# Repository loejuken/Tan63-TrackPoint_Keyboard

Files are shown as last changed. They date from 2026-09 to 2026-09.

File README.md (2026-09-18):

# Tan63

## Building a Trackpoint HHKB Mechanical Keyboard

AKA The ultimate larper keyboard for maximizing productivity
... but ending up just making everything more complicated lol

I love this project though

PCB, Case, and plate are finished. Case and plate CAD files will be uploaded at some point.
I may make a version 2 of the case before uploading to update some design choices and optimize for CNC.

Will upload finished images after final soldering fixes are done. Waiting for time to visit my makerspace nearby.
I've been a bit busy with school

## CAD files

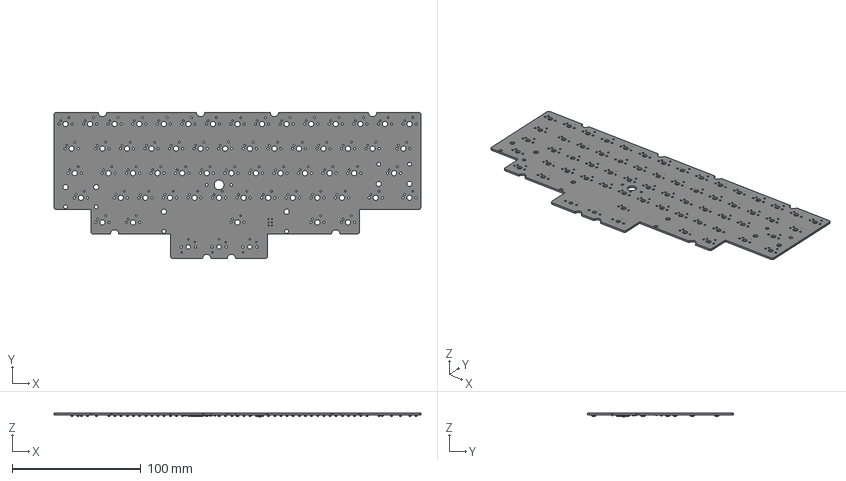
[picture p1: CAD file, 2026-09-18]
pcb.step
284.5 x 113.1 x 3.09 mm
R_0603_1608Metric x 7
D_SOD-123 x 63
C_0603_1608Metric x 8
TQFP-44_10x10mm_P0.8mm
SW_SPST_SKQG_WithStem
Crystal_SMD_3225-4Pin_3.2x2.5mm
ai03-pcb-guide_PCB

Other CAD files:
tan63.FCStd

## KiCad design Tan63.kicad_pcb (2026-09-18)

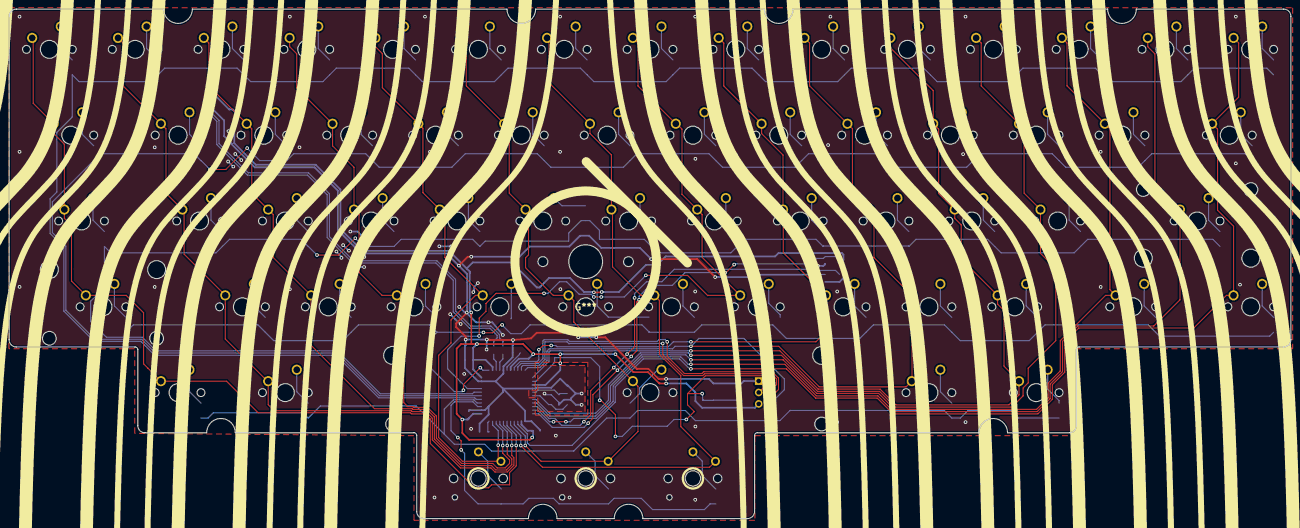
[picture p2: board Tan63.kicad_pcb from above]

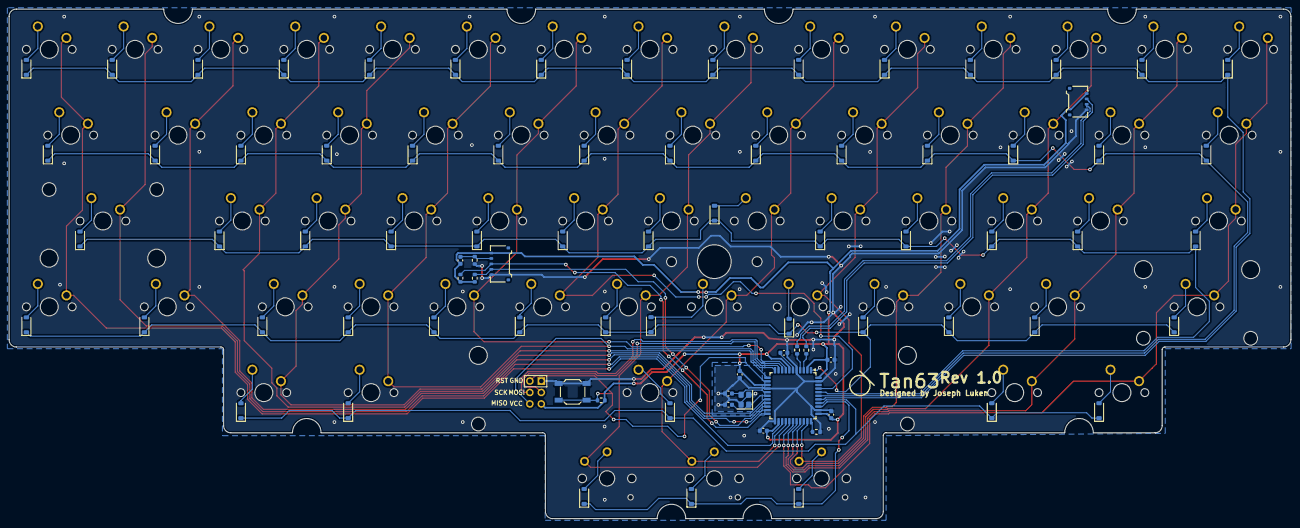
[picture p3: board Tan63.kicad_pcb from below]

Board: 2 copper layers, 284.5 x 113.1 mm, 147 parts (84 on the bottom side), 100 nets.

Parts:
C1, C2: 22pF; C_0603_1608Metric
C3: 1uF; C_0603_1608Metric
C4, C5, C6: 0.1uF; C_0603_1608Metric
C7: 10uF; C_0603_1608Metric
C8: 2.2 uF; C_0603_1608Metric
D1, D2, D3, D4, D5, D6, D7, D8, D9, D10, D11, D12, D13, D14, D15, D16, D17, D18, D19, D20, D21, D22, D23, D24, D25, D26, D27, D28, D29, D30, D31, D32, D33, D34, D35, D36, D37, D38, D39, D40, D41, D42, D43, D44, D45, D46, D47, D48, D49, D50, D51, D52, D53, D54, D55, D56, D57, D58, D59, D60, D61, D62, D63: D; D_SOD-123
J1: Conn_01x04_Socket; Molex_Pico-EZmate_78171-0004_1x04-1MP_P1.20mm_Vertical
J2: AVR-ISP-6; Reset_Pretty-Mask
J3: Conn_01x05_Socket; Molex_Pico-EZmate_78171-0005_1x05-1MP_P1.20mm_Vertical
R1, R4: 10k; R_0603_1608Metric
R2, R3: 22; R_0603_1608Metric
R5: 100k; R_0603_1608Metric
R6, R7: 4.7k; R_0603_1608Metric
Reset1: SW_Push; SW_SPST_SKQG_WithStem
SW1: Esc; MXOnly-1U
SW2: 1; MXOnly-1U
SW3: 2; MXOnly-1U
SW4: 3; MXOnly-1U
SW5: 4; MXOnly-1U
SW6: 5; MXOnly-1U
SW7: 6; MXOnly-1U
SW8: 7; MXOnly-1U
SW9: 8; MXOnly-1U
SW10: 9; MXOnly-1U
SW11: 0; MXOnly-1U
SW12: - _; MXOnly-1U
SW13: = +; MXOnly-1U
SW14: \ |; MXOnly-1U
SW15: MXOnly-1U
SW16: Tab; MXOnly-1.5U
SW17: Q; MXOnly-1U
SW18: W; MXOnly-1U
SW19: E; MXOnly-1U
SW20: R; MXOnly-1U
SW21: T; MXOnly-1U
SW22: Y; MXOnly-1U
SW23: U; MXOnly-1U
SW24: I; MXOnly-1U
SW25: O; MXOnly-1U
SW26: P; MXOnly-1U
SW27: { [; MXOnly-1U
SW28: } ]; MXOnly-1U
SW29: Del; MXOnly-1.5U
SW30: Ctrl; MXOnly-1.75U
SW31: A; MXOnly-1U
SW32: S; MXOnly-1U
SW33: D; MXOnly-1U
SW34: F; MXOnly-1U
SW35: G; MXOnly-1U
SW36: H; MXOnly-1U
SW37: J; MXOnly-1U
SW38: K; MXOnly-1U
SW39: L; MXOnly-1U
SW40: ; :; MXOnly-1U
SW41: ' "; MXOnly-1U
SW42: Return; MXOnly-2.25U
SW43: Shift; MXOnly-2.25U-ReversedStabilizers-NoLED
SW44: Z; MXOnly-1U
SW45: X; MXOnly-1U
SW46: C; MXOnly-1U
SW47: V; MXOnly-1U
SW48: B; MXOnly-1U
SW49: N; MXOnly-1U
SW50: M; MXOnly-1U
SW51: , <; MXOnly-1U
SW52: . >; MXOnly-1U
SW53: / ?; MXOnly-1U
SW54: Shift; MXOnly-1.75U
SW55: Fn; MXOnly-1U
SW56, SW60: Option; MXOnly-1U
SW57, SW59: Super; MXOnly-1.5U
SW58: Space; MXOnly-6U-ReversedStabilizers-NoLED
SW61: Left Mouse; KailhChoc-1.5U
SW62: Middle Mouse; KailhChoc-1U
SW63: Right Mouse; KailhChoc-1.5U
U1: ATmega32U4-A; TQFP-44_10x10mm_P0.8mm
Y1: 16MHz; Crystal_SMD_3225-4Pin_3.2x2.5mm

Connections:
+5V: C4.1, C5.1, C6.1, C7.1, C8.2, J1.1, J2.2 (VCC), J3.5, R1.1, R6.1, R7.2, U1.2 (UVCC), U1.7 (VBUS), U1.14 (VCC), U1.24 (AVCC), U1.34 (VCC), U1.44 (AVCC)
/DN: J1.2, R2.2
/DP: J1.3, R3.1
CLK: J3.3, R7.1, U1.22 (PD5)
Col 0: SW1.1, SW16.1, SW30.1, SW43.1, SW56.1, U1.28 (PB4)
Col 1: SW2.1, SW17.1, SW31.1, SW44.1, SW57.1, U1.29 (PB5)
Col 2: SW3.1, SW18.1, SW32.1, SW45.1, U1.30 (PB6)
Col 3: SW4.1, SW19.1, SW33.1, SW46.1, U1.31 (PC6)
Col 4: SW5.1, SW20.1, SW34.1, SW47.1, SW61.1, U1.32 (PC7)
Col 5: SW6.1, SW21.1, SW35.1, SW48.1, SW58.1, SW62.1, U1.26 (PD6)
Col 6: SW7.1, SW22.1, SW36.1, SW49.1, SW63.1, U1.27 (PD7)
Col 7: SW8.1, SW23.1, SW37.1, SW50.1, U1.41 (PF0)
Col 8: SW9.1, SW24.1, SW38.1, SW51.1, U1.8 (PB0)
Col 9: J2.1 (MISO), SW10.1, SW25.1, SW39.1, SW52.1, SW59.1, U1.11 (PB3)
Col 10: SW11.1, SW26.1, SW40.1, SW53.1, SW60.1, U1.12 (PB7)
Col 11: SW12.1, SW27.1, SW41.1, U1.18 (PD0)
Col 12: SW13.1, SW28.1, SW54.1, U1.19 (PD1)
Col 13: SW14.1, SW42.1, U1.21 (PD3)
Col 14: SW15.1, SW29.1, SW55.1, U1.25 (PD4)
D: J3.2, R6.2, U1.20 (PD2)
D+: R3.2, U1.4 (D+)
D-: R2.1, U1.3 (D-)
GND: C1.1, C2.1, C3.2, C4.2, C5.2, C6.2, C7.2, J1.4, J2.6 (GND), J3.1, R4.1, R5.1, Reset1.1, U1.5 (UGND), U1.15 (GND), U1.23 (GND), U1.35 (GND), U1.43 (GND), Y1.2 (G), Y1.4 (G)
MOSI: J2.4 (MOSI), U1.10 (PB2)
unnamed: D1.2 (A), SW1.2
unnamed: D2.2 (A), SW2.2
unnamed: D3.2 (A), SW3.2
unnamed: D4.2 (A), SW4.2
unnamed: D5.2 (A), SW5.2
unnamed: D6.2 (A), SW6.2
unnamed: D7.2 (A), SW7.2
unnamed: D8.2 (A), SW8.2
unnamed: D9.2 (A), SW9.2
unnamed: D10.2 (A), SW10.2
unnamed: D11.2 (A), SW11.2
unnamed: D12.2 (A), SW12.2
unnamed: D13.2 (A), SW13.2
unnamed: D14.2 (A), SW14.2
unnamed: D15.2 (A), SW15.2
unnamed: D16.2 (A), SW16.2
unnamed: D17.2 (A), SW17.2
unnamed: D18.2 (A), SW18.2
unnamed: D19.2 (A), SW19.2
unnamed: D20.2 (A), SW20.2
unnamed: D21.2 (A), SW21.2
unnamed: D22.2 (A), SW22.2
unnamed: D23.2 (A), SW23.2
unnamed: D24.2 (A), SW24.2
unnamed: D25.2 (A), SW25.2
unnamed: D26.2 (A), SW26.2
unnamed: D27.2 (A), SW27.2
unnamed: D28.2 (A), SW28.2
unnamed: D29.2 (A), SW29.2
unnamed: D30.2 (A), SW30.2
unnamed: D31.2 (A), SW31.2
unnamed: D32.2 (A), SW32.2
unnamed: D33.2 (A), SW33.2
unnamed: D34.2 (A), SW34.2
unnamed: D35.2 (A), SW35.2
unnamed: D36.2 (A), SW36.2
unnamed: D37.2 (A), SW37.2
unnamed: D38.2 (A), SW38.2
unnamed: D39.2 (A), SW39.2
unnamed: D40.2 (A), SW40.2
unnamed: D41.2 (A), SW41.2
unnamed: D42.2 (A), SW42.2
unnamed: D43.2 (A), SW43.2
unnamed: D44.2 (A), SW44.2
unnamed: D45.2 (A), SW45.2
unnamed: D46.2 (A), SW46.2
unnamed: D47.2 (A), SW47.2
unnamed: D48.2 (A), SW48.2
unnamed: D49.2 (A), SW49.2
unnamed: D50.2 (A), SW50.2
unnamed: D51.2 (A), SW51.2
unnamed: D52.2 (A), SW52.2
unnamed: D53.2 (A), SW53.2
unnamed: D54.2 (A), SW54.2
unnamed: D55.2 (A), SW55.2
unnamed: D56.2 (A), SW56.2
unnamed: D57.2 (A), SW57.2
unnamed: D58.2 (A), SW58.2
unnamed: D59.2 (A), SW59.2
unnamed: D60.2 (A), SW60.2
unnamed: D61.2 (A), SW61.2
unnamed: D62.2 (A), SW62.2
unnamed: D63.2 (A), SW63.2
unnamed: C3.1, U1.6 (UCAP)
unnamed: R4.2, U1.33 (~HWB/PE2)
RESET: J2.5 (~RST), R1.2, Reset1.2, U1.13 (~RESET)
RST: C8.1, J3.4, R5.2
Row 0: D1.1 (K), D2.1 (K), D3.1 (K), D4.1 (K), D5.1 (K), D6.1 (K), D7.1 (K), D8.1 (K), D9.1 (K), D10.1 (K), D11.1 (K), D12.1 (K), D13.1 (K), D14.1 (K), D15.1 (K), U1.38 (PF5)
Row 1: D16.1 (K), D17.1 (K), D18.1 (K), D19.1 (K), D20.1 (K), D21.1 (K), D22.1 (K), D23.1 (K), D24.1 (K), D25.1 (K), D26.1 (K), D27.1 (K), D28.1 (K), D29.1 (K), U1.39 (PF4)
Row 2: D30.1 (K), D31.1 (K), D32.1 (K), D33.1 (K), D34.1 (K), D35.1 (K), D36.1 (K), D37.1 (K), D38.1 (K), D39.1 (K), D40.1 (K), D41.1 (K), D42.1 (K), U1.40 (PF1)
Row 3: D43.1 (K), D44.1 (K), D45.1 (K), D46.1 (K), D47.1 (K), D48.1 (K), D49.1 (K), D50.1 (K), D51.1 (K), D52.1 (K), D53.1 (K), D54.1 (K), D55.1 (K), U1.1 (PE6)
Row 4: D56.1 (K), D57.1 (K), D58.1 (K), D59.1 (K), D60.1 (K), U1.37 (PF6)
Row 5: D61.1 (K), D62.1 (K), D63.1 (K), U1.36 (PF7)
SCK: J2.3 (SCK), U1.9 (PB1)
XTAL1: C1.2, U1.17 (XTAL1), Y1.1
XTAL2: C2.2, U1.16 (XTAL2), Y1.3

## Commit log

2026-09-18 Adding Official Keybaord naming to files
    [Tan63.kicad_pcb, Tan63.kicad_sch, pcb.step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]
2026-09-18 Update README with project status and future plans
    Added a note about potential version 2 of the case design.
